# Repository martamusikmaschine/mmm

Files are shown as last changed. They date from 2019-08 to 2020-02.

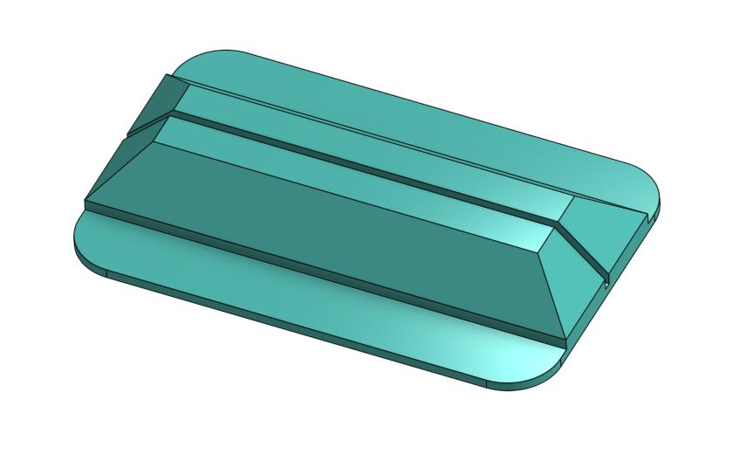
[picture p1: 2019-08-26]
3d/rfid_tag_44_29_foil_holder.jpg

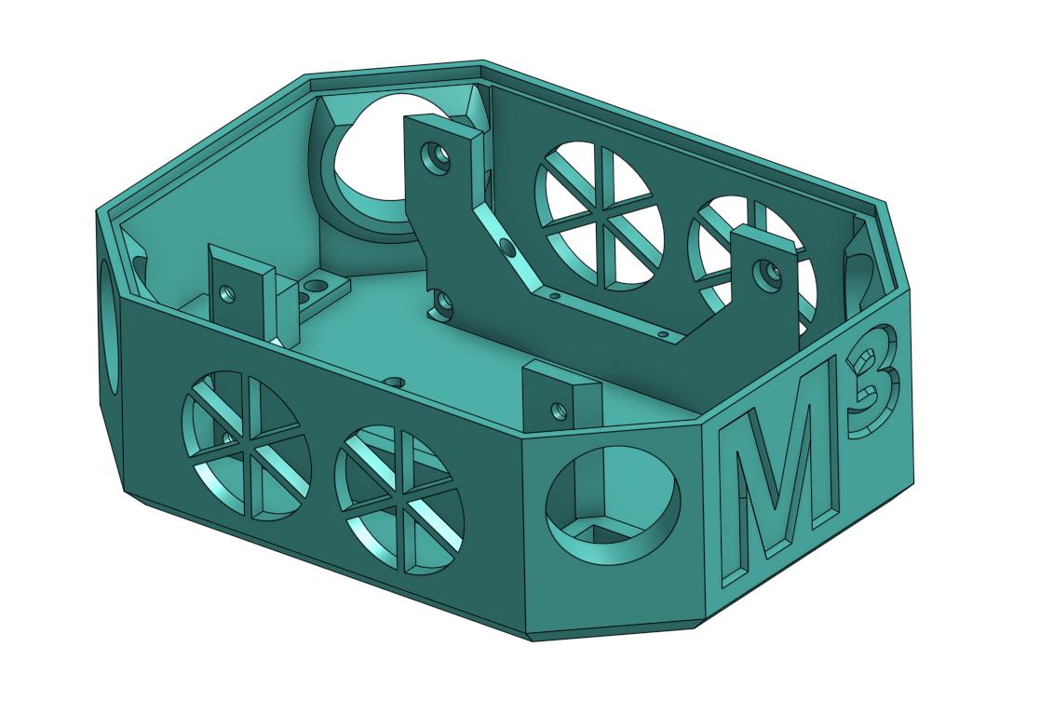
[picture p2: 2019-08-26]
3d/main_body.jpg

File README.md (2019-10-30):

# Marta Musik Maschine
Before doing anything, checkout the associated blog post series at [martamusikmaschine.com](https://martamusikmaschine.com).

Marta Musik Maschine is a DIY, RFID enabled, multi-purpose, audio and light device for kids. It's open source and you can build one yourself. It's not hard at all, I promise.

This repository contains all the code needed on the Raspberry Pi, a KiCad project that enables you to etch/order a PCB and a few stl models that you can print on a 3D printer.

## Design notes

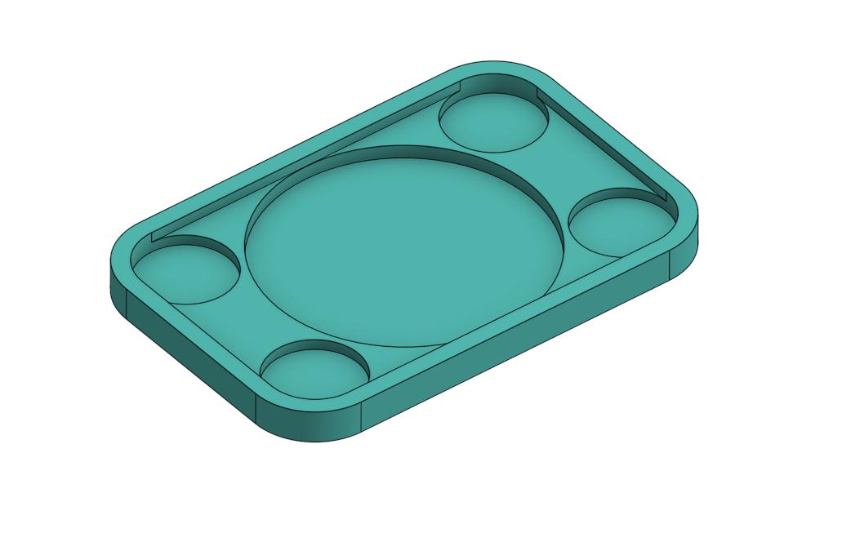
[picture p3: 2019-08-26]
3d/rfid_tag_44_29_base.jpg

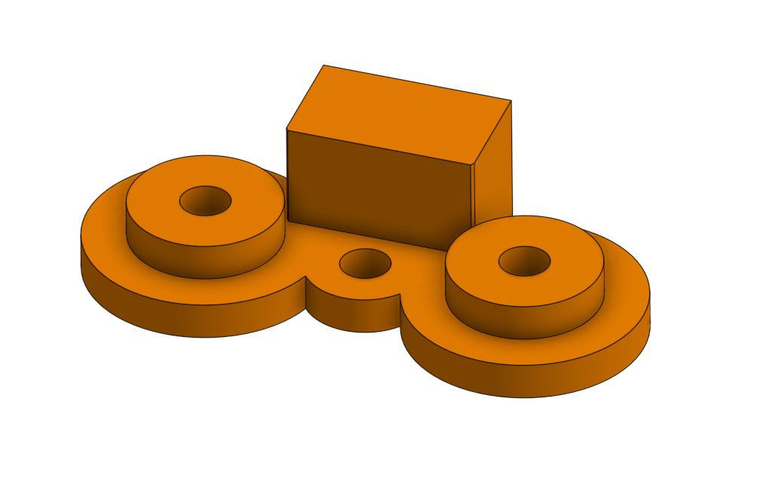
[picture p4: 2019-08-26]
3d/rfid_reader_magnet_cap.jpg

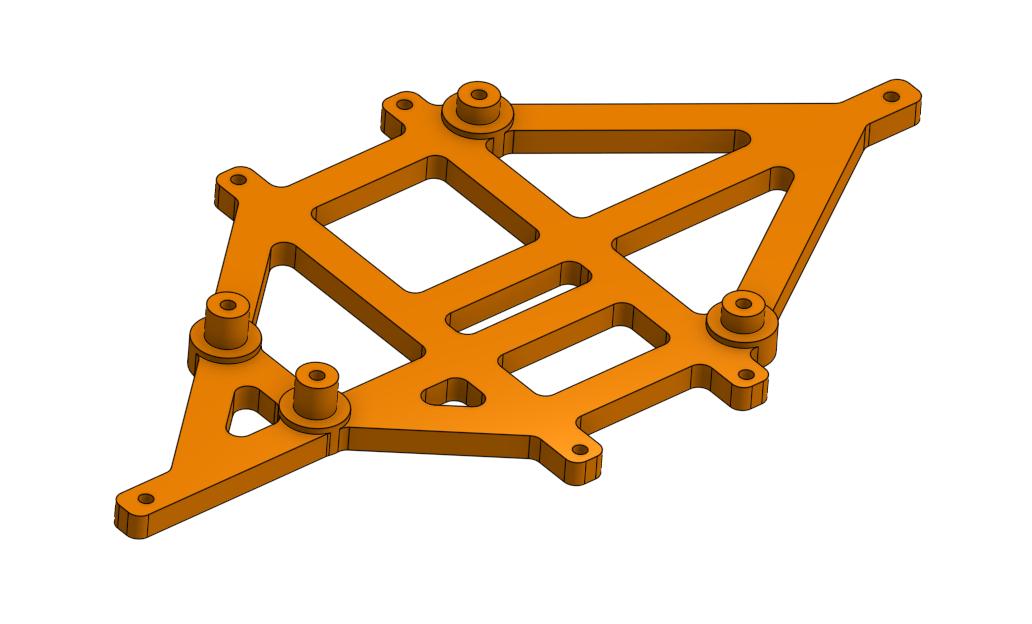
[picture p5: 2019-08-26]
3d/pcb_holder.jpg

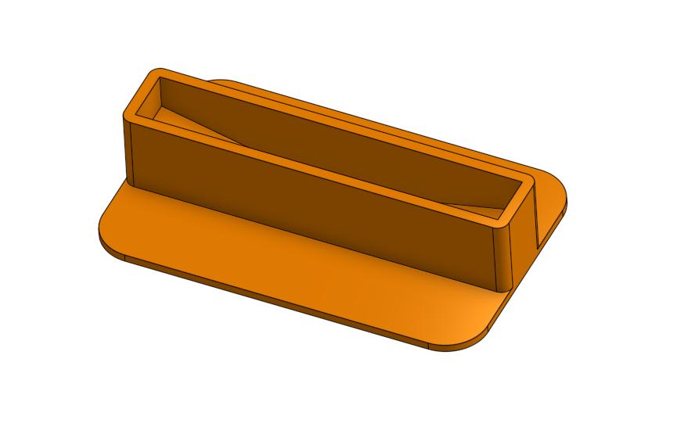
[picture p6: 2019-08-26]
3d/rfid_tag_44_29_photo_holder.jpg

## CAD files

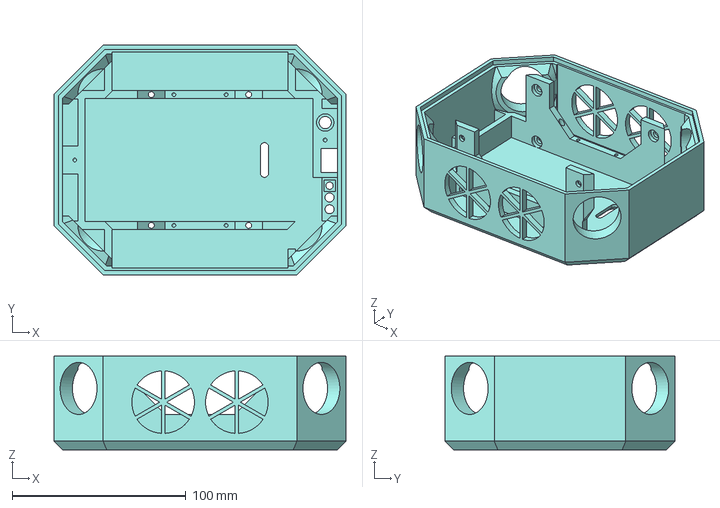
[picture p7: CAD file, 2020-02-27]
3d/main_body.step
168.0 x 132.2 x 54.0 mm

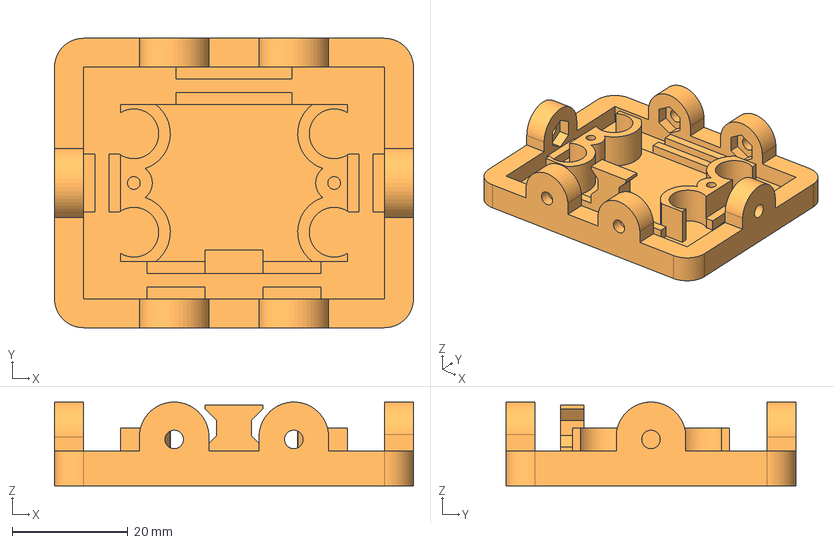
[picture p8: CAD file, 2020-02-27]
3d/rfid_reader_main.step
62.0 x 50.0 x 14.5 mm

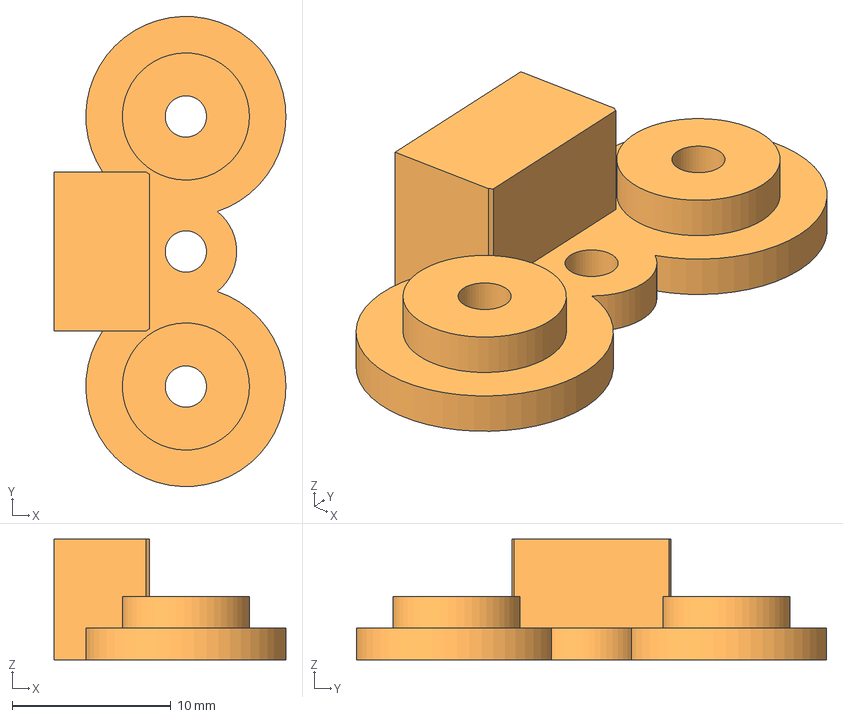
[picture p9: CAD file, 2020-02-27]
3d/rifd_reader_magnet_cap.step
14.6 x 29.6 x 7.60 mm

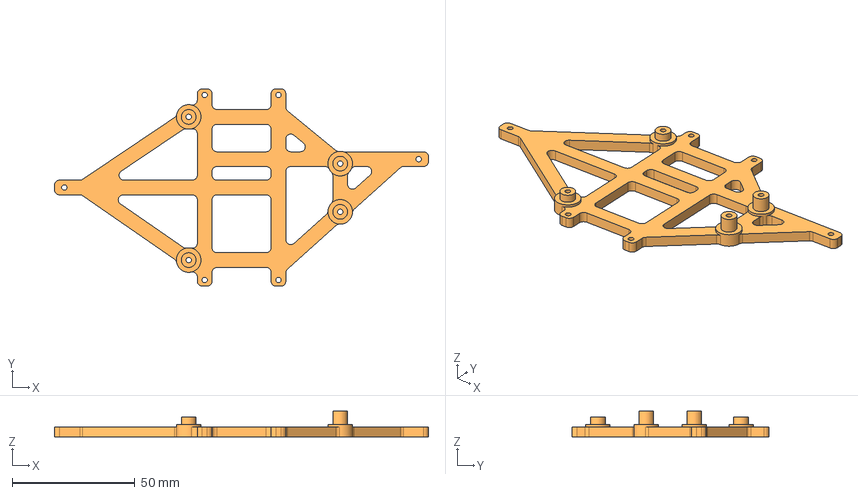
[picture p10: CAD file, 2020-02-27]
3d/pcb_holder.step
152.0 x 80.2 x 10.5 mm

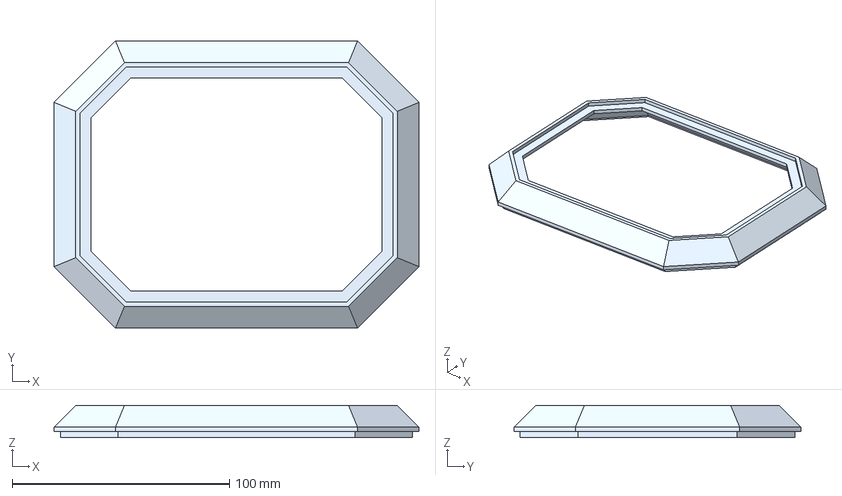
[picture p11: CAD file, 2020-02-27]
3d/led_ring.step
168.0 x 132.2 x 14.8 mm

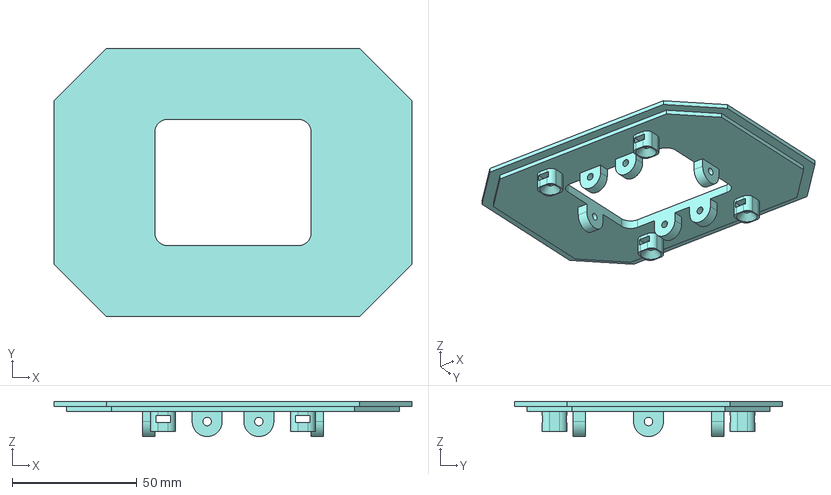
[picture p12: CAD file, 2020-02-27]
3d/top_plate.step
143.2 x 107.4 x 14.0 mm

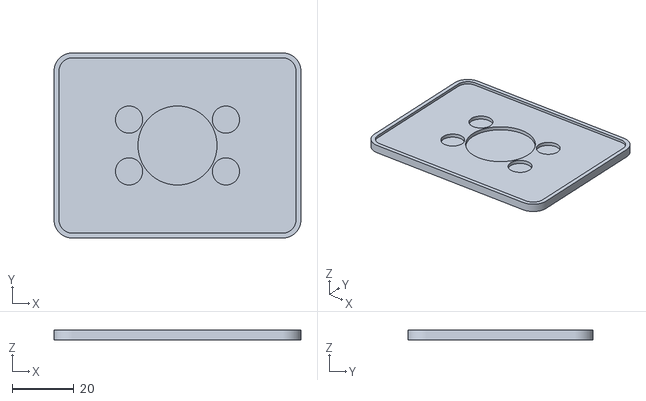
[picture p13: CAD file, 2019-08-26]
3d/rfid_tag_80_60_base.stl
80.0 x 60.0 x 3.10

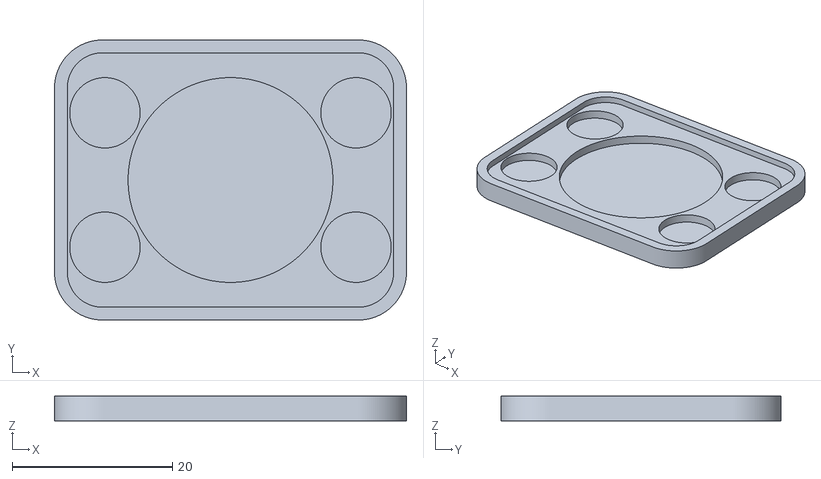
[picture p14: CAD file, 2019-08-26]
3d/rfid_tag_44_35_base.stl
44.0 x 35.0 x 3.10

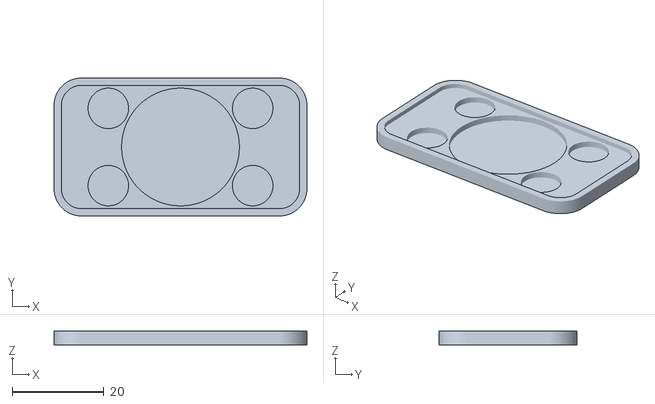
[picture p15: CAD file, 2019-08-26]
3d/rfid_tag_55_30_base.stl
55.0 x 30.0 x 3.10

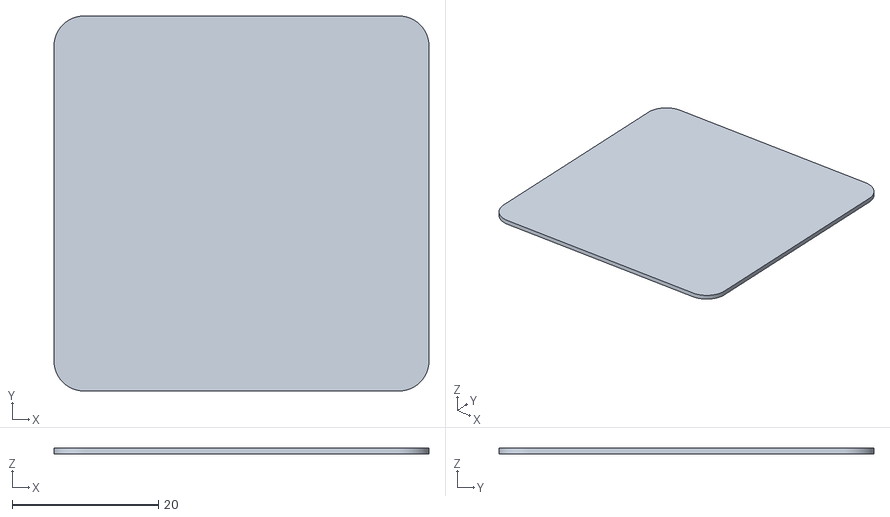
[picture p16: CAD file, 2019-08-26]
3d/rfid_tag_55_55_cap.stl
51.2 x 51.2 x 0.8

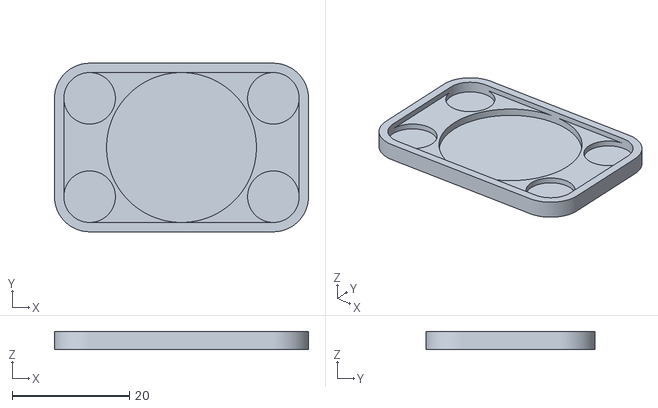
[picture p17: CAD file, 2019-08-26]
3d/rfid_tag_44_29_base.stl
43.4 x 28.8 x 3.10

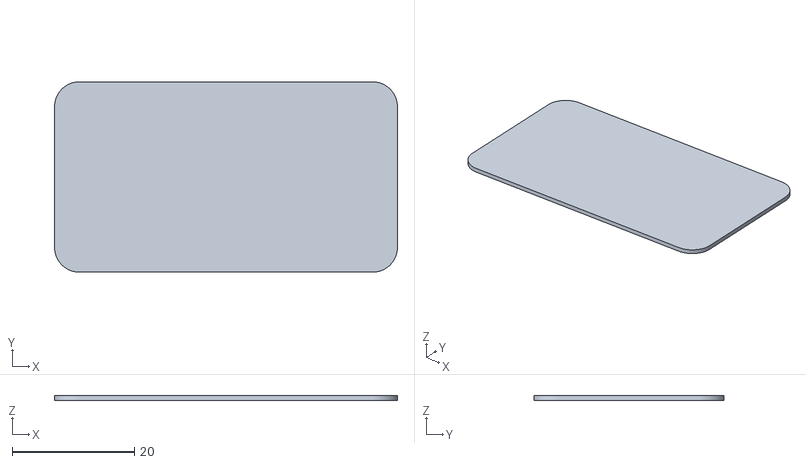
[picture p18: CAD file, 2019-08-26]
3d/rfid_tag_60_35_cap.stl
56.2 x 31.2 x 0.8

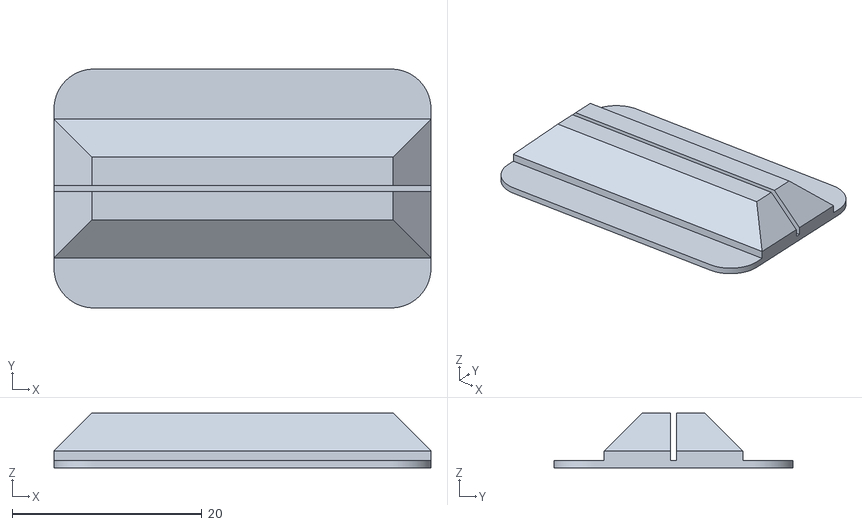
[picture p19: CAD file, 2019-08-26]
3d/rfid_tag_44_29_foil_holder.stl
39.8 x 25.2 x 5.80

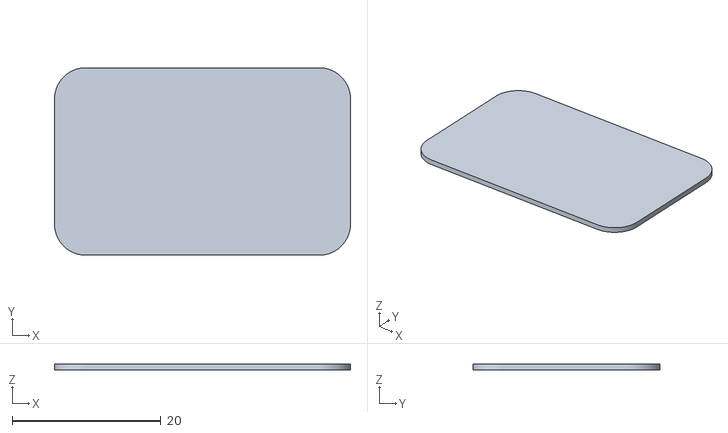
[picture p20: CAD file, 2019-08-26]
3d/rfid_tag_44_29_cap.stl
39.8 x 25.2 x 0.8

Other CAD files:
3d/rfid_reader_magnet_cap.iges
3d/rfid_tag_44_29_photo_holder.stl
3d/rfid_tag_50_30_base.stl
3d/rfid_tag_80_30_cap.stl
3d/led_ring.iges
3d/led_ring.stl
3d/main_body.iges
3d/main_body.stl
3d/pcb_holder.iges
3d/pcb_holder.stl
3d/rfid_reader_magnet_cap.stl
3d/rfid_reader_main.iges
3d/rfid_reader_main.stl
3d/rfid_tag_44_35_cap.stl
3d/rfid_tag_50_30_cap.stl
3d/rfid_tag_50_35_base.stl
3d/rfid_tag_50_35_cap.stl
3d/rfid_tag_50_50_base.stl
3d/rfid_tag_50_50_cap.stl
3d/rfid_tag_55_30_cap.stl
3d/rfid_tag_55_55_base.stl
3d/rfid_tag_60_35_base.stl
3d/rfid_tag_62_32_base.stl
3d/rfid_tag_62_32_cap.stl
3d/rfid_tag_80_30_base.stl
3d/rfid_tag_80_60_cap.stl
3d/top_plate.iges
3d/top_plate.stl

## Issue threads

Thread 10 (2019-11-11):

CAD files

nick-traeger, 2019-11-11:
Hello, thanks for publishing this great project! I would like to build a similar box and change the design of the box a bit. Is it possible to get the CAD files - not just the STL files?

martamusikmaschine, 2020-02-27:
Hey, so sorry. I didn't get any notification and haven't looked at the repository for quite some time. I'll upload IGES and STEP files for the main components as well. Unfortunately there's no way to export CAD files from OnShape.

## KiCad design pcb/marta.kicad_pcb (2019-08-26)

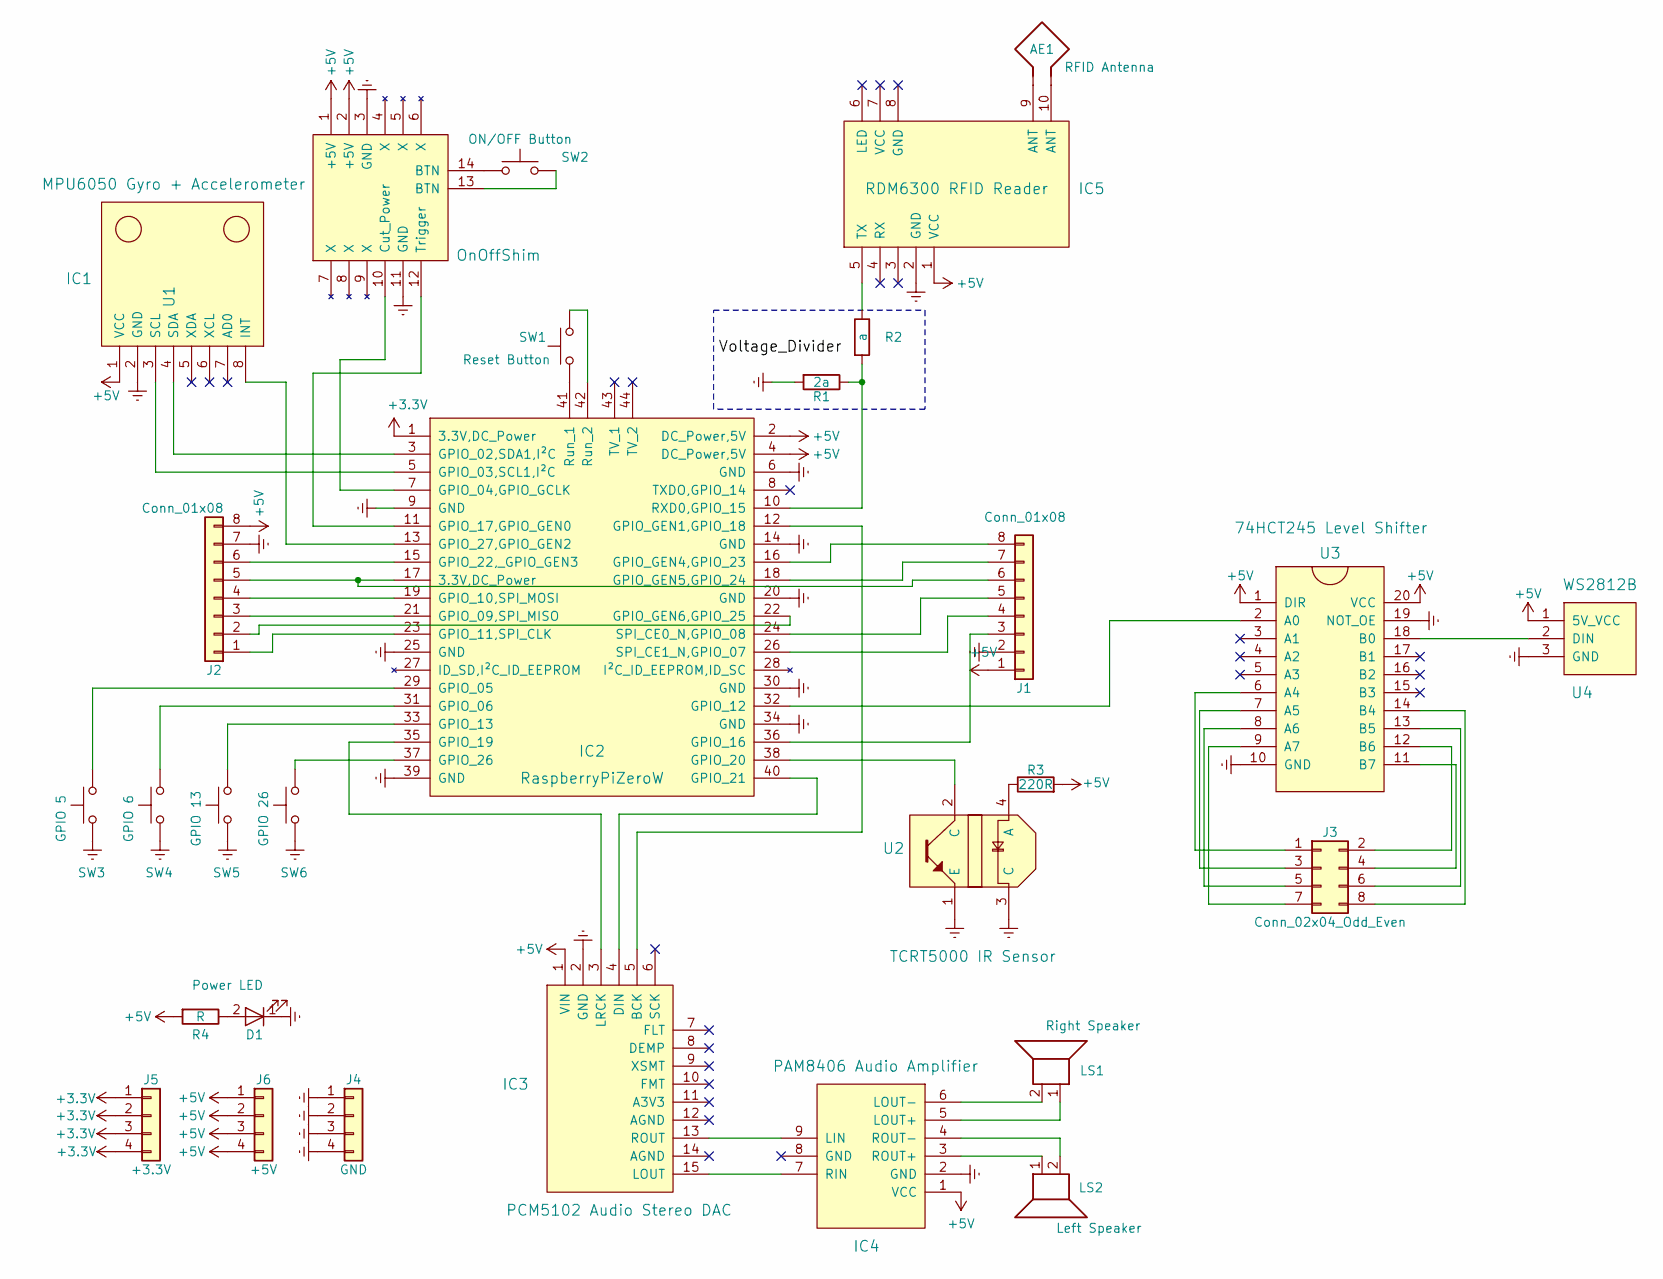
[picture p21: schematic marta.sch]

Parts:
AE1: RFID Antenna; JST_XH_B02B-XH-A_02x2.50mm_Straight
D1: Power LED; JST_XH_B02B-XH-A_02x2.50mm_Straight
IC1: MPU6050 Gyro + Accelerometer; MPU6050
IC2: RaspberryPiZeroW; RaspberryPiZeroW_UpSideDown
IC3: PCM5102 Audio Stereo DAC; PCM5102
IC4: PAM8406 Audio Amplifier; PAM8406
IC5: RDM6300 RFID Reader; RDM6300
J1, J2: Conn_01x08; JST_XH_B08B-XH-A_08x2.50mm_Straight
J3: Conn_02x04_Odd_Even; Pin_Header_Straight_2x04_Pitch2.54mm
J4: GND; Pin_Header_Straight_1x04_Pitch2.54mm
J5: +3.3V; Pin_Header_Straight_1x04_Pitch2.54mm
J6: +5V; Pin_Header_Straight_1x04_Pitch2.54mm
LS1: Right Speaker; JST_XH_B02B-XH-A_02x2.50mm_Straight
LS2: Left Speaker; JST_XH_B02B-XH-A_02x2.50mm_Straight
R1: 2a; R_Axial_DIN0207_L6.3mm_D2.5mm_P10.16mm_Horizontal
R2: a; R_Axial_DIN0207_L6.3mm_D2.5mm_P10.16mm_Horizontal
R3: 220R; R_Axial_DIN0207_L6.3mm_D2.5mm_P10.16mm_Horizontal
R4: R; R_Axial_DIN0207_L6.3mm_D2.5mm_P10.16mm_Horizontal
SW1: Reset Button; JST_XH_B02B-XH-A_02x2.50mm_Straight
SW2: ON/OFF Button; JST_XH_B02B-XH-A_02x2.50mm_Straight
SW3: GPIO 5; JST_XH_B02B-XH-A_02x2.50mm_Straight
SW4: GPIO 6; JST_XH_B02B-XH-A_02x2.50mm_Straight
SW5: GPIO 13; JST_XH_B02B-XH-A_02x2.50mm_Straight
SW6: GPIO 26; JST_XH_B02B-XH-A_02x2.50mm_Straight
U1: OnOffShim
U2: TCRT5000 IR Sensor; JST_XH_B04B-XH-A_04x2.50mm_Straight
U3: 74HCT245 Level Shifter; DIP-20_W7.62mm
U4: WS2812B; Pin_Header_Straight_1x03_Pitch2.54mm

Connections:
+3V3: IC2.1 (3.3V,DC_Power), J5.1, J5.2, J5.3, J5.4
+5V: IC1.1 (VCC), IC2.2 (DC_Power,5V), IC2.4 (DC_Power,5V), IC3.1 (VIN), IC4.1 (VCC), IC5.1 (VCC), J1.1, J2.8, J6.1, J6.2, J6.3, J6.4, R3.2, R4.2, U1.1 (+5V), U1.2 (+5V), U3.1 (DIR), U3.20 (VCC), U4.1 (5V_VCC)
GNDREF: D1.1 (K), IC1.2 (GND), IC2.6 (GND), IC2.9 (GND), IC2.14 (GND), IC2.20 (GND), IC2.25 (GND), IC2.30 (GND), IC2.34 (GND), IC2.39 (GND), IC3.2 (GND), IC4.2 (GND), IC5.2 (GND), J1.2, J2.7, J4.1, J4.2, J4.3, J4.4, R1.2, SW3.1, SW4.1, SW5.1, SW6.1, U1.3 (GND), U1.11 (GND), U2.1 (E), U2.3 (C), U3.10 (GND), U3.19 (NOT_OE), U4.3 (GND)
unnamed: AE1.1, IC5.9 (ANT)
unnamed: AE1.2, IC5.10 (ANT)
unnamed: D1.2 (A), R4.1
unnamed: IC1.3 (SCL), IC2.5 (GPIO_03,SCL1,I²C)
unnamed: IC1.4 (SDA), IC2.3 (GPIO_02,SDA1,I²C)
unnamed: IC1.8 (INT), IC2.13 (GPIO_27,GPIO_GEN2)
unnamed: IC2.7 (GPIO_04,GPIO_GCLK), U1.10 (Cut_Power)
unnamed: IC2.10 (RXD0,GPIO_15), R1.1, R2.2
unnamed: IC2.11 (GPIO_17,GPIO_GEN0), U1.12 (Trigger)
unnamed: IC2.12 (GPIO_GEN1,GPIO_18), IC3.5 (BCK)
unnamed: IC2.15 (GPIO_22,_GPIO_GEN3), J2.6
unnamed: IC2.16 (GPIO_GEN4,GPIO_23), J1.8
unnamed: IC2.17 (3.3V,DC_Power), J1.6, J2.5
unnamed: IC2.18 (GPIO_GEN5,GPIO_24), J1.7
unnamed: IC2.19 (GPIO_10,SPI_MOSI), J2.4
unnamed: IC2.21 (GPIO_09,SPI_MISO), J2.3
unnamed: IC2.22 (GPIO_GEN6,GPIO_25), J2.2
unnamed: IC2.23 (GPIO_11,SPI_CLK), J2.1
unnamed: IC2.24 (SPI_CE0_N,GPIO_08), J1.5
unnamed: IC2.26 (SPI_CE1_N,GPIO_07), J1.4
unnamed: IC2.29 (GPIO_05), SW3.2
unnamed: IC2.31 (GPIO_06), SW4.2
unnamed: IC2.32 (GPIO_12), U3.2 (A0)
unnamed: IC2.33 (GPIO_13), SW5.2
unnamed: IC2.35 (GPIO_19), IC3.3 (LRCK)
unnamed: IC2.36 (GPIO_16), J1.3
unnamed: IC2.37 (GPIO_26), SW6.2
unnamed: IC2.38 (GPIO_20), U2.2 (C)
unnamed: IC2.40 (GPIO_21), IC3.4 (DIN)
unnamed: IC2.41 (Run_1), SW1.1
unnamed: IC2.42 (Run_2), SW1.2
unnamed: IC3.13 (ROUT), IC4.9 (LIN)
unnamed: IC3.15 (LOUT), IC4.7 (RIN)
unnamed: IC4.3 (ROUT+), LS2.1
unnamed: IC4.4 (ROUT-), LS2.2
unnamed: IC4.5 (LOUT+), LS1.1
unnamed: IC4.6 (LOUT-), LS1.2
unnamed: IC5.5 (TX), R2.1
unnamed: J3.1, U3.6 (A4)
unnamed: J3.2, U3.12 (B6)
unnamed: J3.3, U3.7 (A5)
unnamed: J3.4, U3.11 (B7)
unnamed: J3.5, U3.8 (A6)
unnamed: J3.6, U3.13 (B5)
unnamed: J3.7, U3.9 (A7)
unnamed: J3.8, U3.14 (B4)
unnamed: R3.1, U2.4 (A)
unnamed: SW2.1, U1.14 (BTN)
unnamed: SW2.2, U1.13 (BTN)
unnamed: U3.18 (B0), U4.2 (DIN)

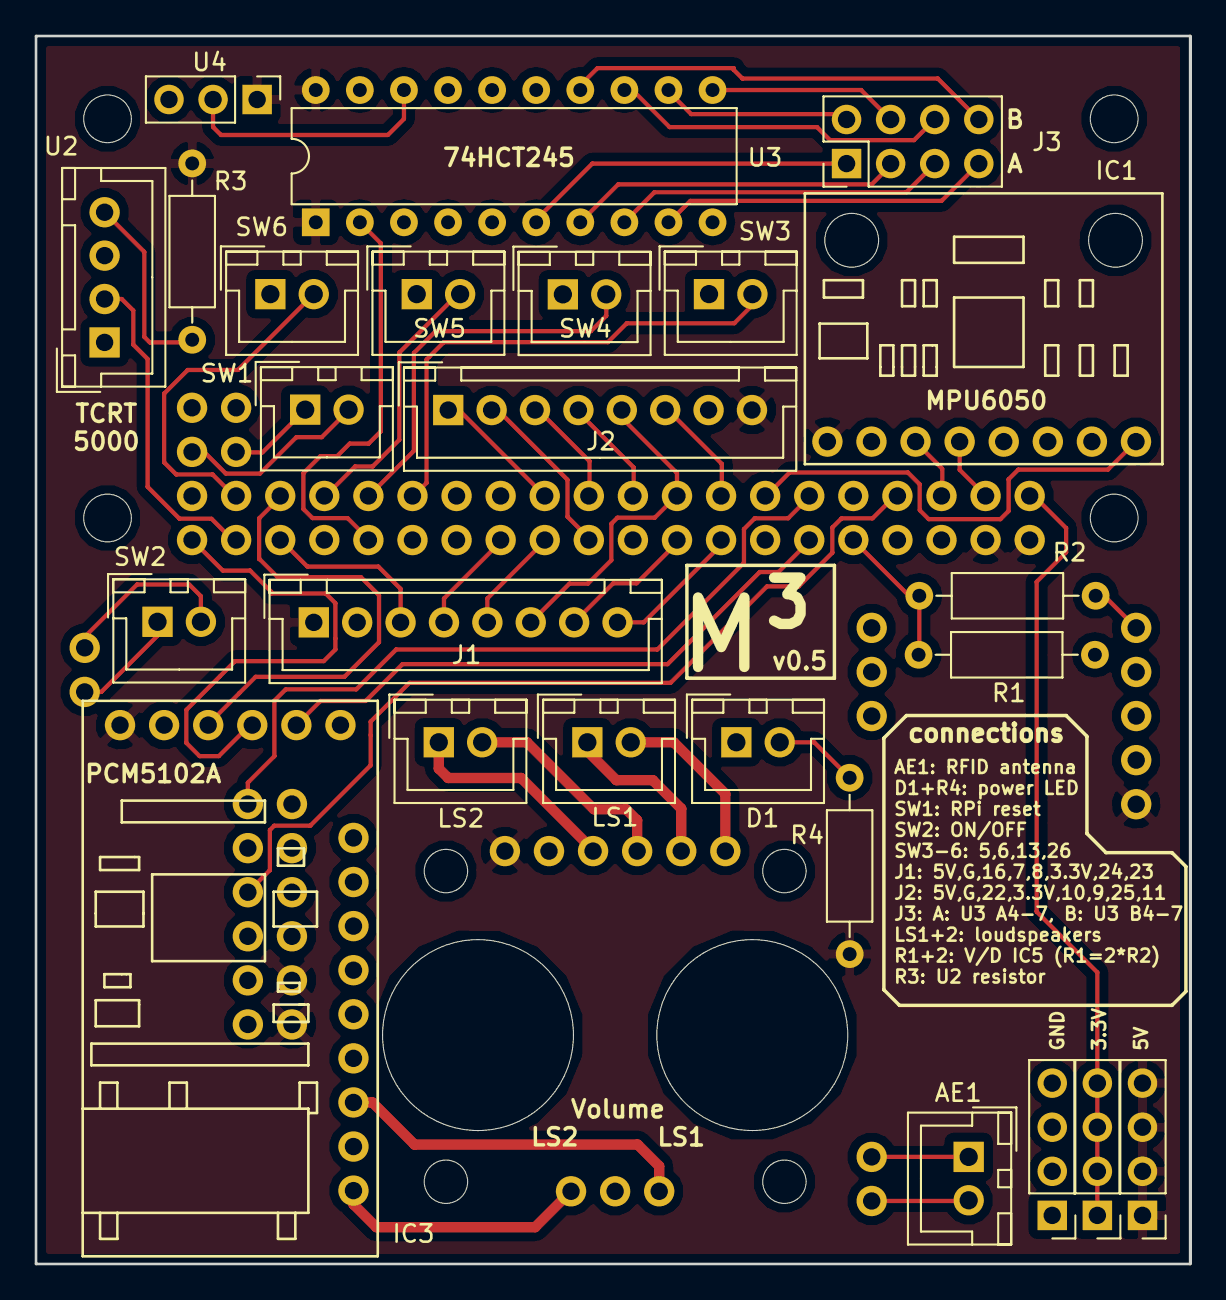
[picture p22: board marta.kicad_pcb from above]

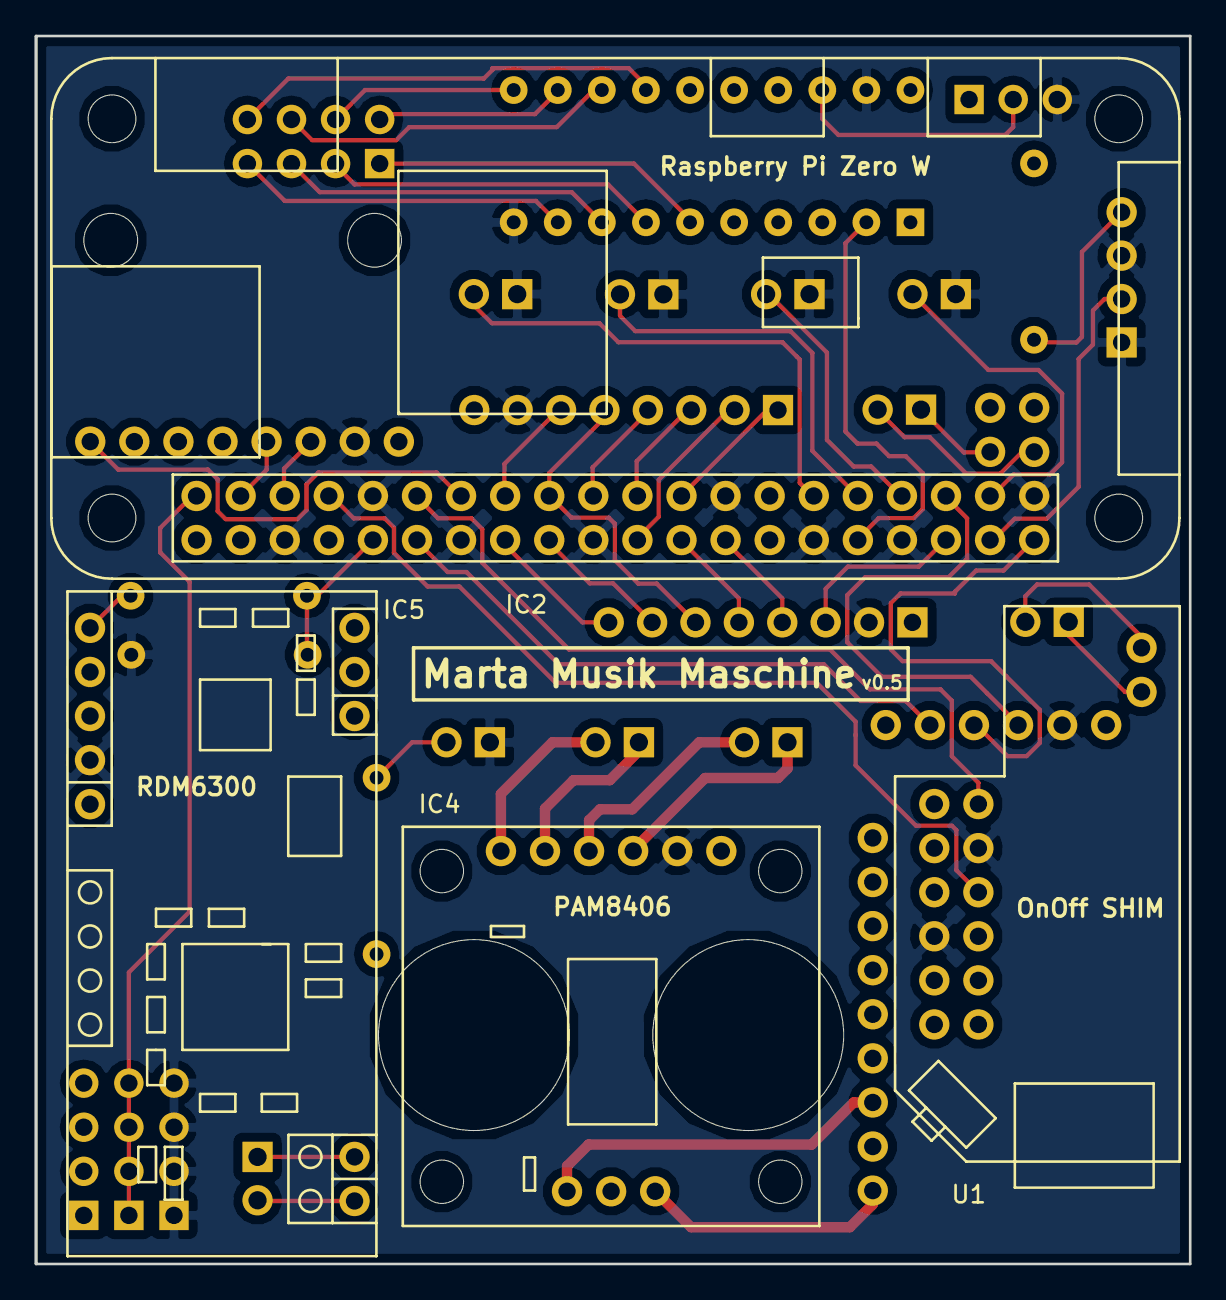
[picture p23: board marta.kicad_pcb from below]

Board: 2 copper layers, 66.5 x 70.8 mm, 29 parts (4 on the bottom side), 53 nets.

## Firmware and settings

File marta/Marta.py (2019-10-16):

# system
from logging import handlers, getLogger, DEBUG, Formatter, StreamHandler
from sys import stdout, argv
from Queue import Queue, Empty
from time import sleep, strftime
from signal import signal, SIGINT
from os import environ
from monotonic import monotonic as mtime
import traceback

import Buttons
from MartaHandler import MartaHandler
from LEDStrip import LEDStrip
from MPG123 import MPG123Player
from MPU import MPU
from RFIDReader import RFIDReader
from TagToHandler import TAG_TO_HANDLER

debug = getLogger('     Marta').debug

MARTA_BASE_DIR = environ["MARTA"]


class Marta(object):
    ################
    # EVENTS
    EVENT_SONG_STOPPED = 0
    EVENT_RFID_TAG = 1
    EVENT_BUTTON = 2
    EVENT_MPG123_ERROR = 3
    EVENT_ROTATION = 4
    EVENT_INTERRUPT = 5

    EXIT_DEBUG = 2

    EVENT_HUMAN_READABLE = [
        "EVENT_SONG_STOPPED",
        "EVENT_TAG",
        "EVENT_BUTTON",
        "EVENT_MPG123_ERROR",
        "EVENT_ROTATION",
        "EVENT_INTERRUPT"
    ]

    ################
    # SPECIAL TAGS

    INTERRUPT_TAG = "5600C7AC4B76"

    ################
    # AUDIO

    START_SOUND_PATH = MARTA_BASE_DIR + "/audio/system/startup.mp3"
    SHUTDOWN_SOUND_PATH = MARTA_BASE_DIR + "/audio/system/shutdown.mp3"
    SYSTEM_SOUND_VOLUME = 2

    def __init__(self):
        self.__message_queue = Queue()
        Buttons.setup_gpio(lambda pin, millis: self.__message_queue.put([Marta.EVENT_BUTTON, pin, millis]))

        if Buttons.is_pushed(Buttons.POWER_BUTTON) and Buttons.is_pushed(Buttons.RED_BUTTON):
            Buttons.terminate()
            debug("Early user interrupt!")
            exit(Marta.EXIT_DEBUG)

        self.player = MPG123Player(lambda: self.__message_queue.put([Marta.EVENT_SONG_STOPPED]),
                                   lambda: self.__message_queue.put([Marta.EVENT_MPG123_ERROR]),
                                   volume=Marta.SYSTEM_SOUND_VOLUME)

        self.leds = LEDStrip()

        self.player.load_track_from_file(Marta.START_SOUND_PATH)
        self.leds.startup()
        self.player.play_track()

        # hacky because MPG123Player is async
        while not self.player.is_track_playing():
            sleep(0.05)

        # True = GPIO.HIGH = 1
        # False = GPIO.LOW = 0
        g = True
        while self.player.is_track_playing():
            Buttons.set_status_led(g)
            sleep(0.2)
            g = not g

        Buttons.set_status_led(0)

        # Empty q after short period of time (player stop event and button pushes)
        sleep(0.1)
        while not self.__message_queue.empty():
            self.__message_queue.get(block=False)

        self.mpu = MPU(period=1, threshold=5,
                       rotation_receiver=lambda x, y: self.__message_queue.put([Marta.EVENT_ROTATION, x, y]))

        self.rfid_reader = RFIDReader(lambda tag: self.__message_queue.put([Marta.EVENT_RFID_TAG, tag]))

    def interrupt(self):
        self.__message_queue.put([Marta.EVENT_INTERRUPT])

    def message_loop(self):

        current_handler = TAG_TO_HANDLER["default"].get_instance(self)
        max_mono_time = mtime() + current_handler.initialize()

        while True:
            now = mtime()
            debug("now = " + str(now))

            if now >= max_mono_time:
                debug("timeout occurred")
                break

            timeout = max_mono_time - now
            debug("waiting for " + str(timeout))
            try:
                msg = self.__message_queue.get(block=True, timeout=timeout)
            except Empty:
                # If a time change (due to network time availability) occurs while waiting for an event,
                # Queue.get will return Empty early:

                # 14:46:31.368 | main | now = 54.502526
                # 14:46:31.380 | main | waiting for 299.955775
                # -- NOW THE TIME CHANGE OCCURS --
                # 19:29:13.403 | main | timeout @ 67.323505
                # 19:29:13.410 | main | Terminating!

                # Instead of breaking here, we just continue, because we have another check on top of this function
                #  which checks the timeout again but using a monotonic timer
                debug("possible timeout @ " + str(mtime()))
                continue

            event = msg[0]
            params = msg[1:]

            if event == Marta.EVENT_INTERRUPT:
                debug("Critical: Interrupt event!")
                break

            elif event == Marta.EVENT_MPG123_ERROR:
                debug("Critical: MPG123 error event!")
                break

            elif event == Marta.EVENT_BUTTON and params[0] == Buttons.POWER_BUTTON:
                debug("Critical: Power button event!")
                break

            elif event == Marta.EVENT_RFID_TAG:
                tag = params[0]

                if tag == Marta.INTERRUPT_TAG:
                    debug("Critical: Interrupt tag event!")
                    exit(Marta.EXIT_DEBUG)
                    break

                if tag in TAG_TO_HANDLER:
                    current_handler.uninitialize()
                    current_handler = TAG_TO_HANDLER[tag].get_instance(self)
                    current_handler.initialize()

            debug(Marta.EVENT_HUMAN_READABLE[event] + ": " + str(params))
            if event == Marta.EVENT_ROTATION:
                return_val = current_handler.rotation_event(params[0], params[1])
            elif event == Marta.EVENT_SONG_STOPPED:
                return_val = current_handler.player_stop_event()
            elif event == Marta.EVENT_RFID_TAG:
                return_val = current_handler.rfid_tag_event(params[0])
            elif event == Marta.EVENT_BUTTON:
                return_val = current_handler.button_event(params[0], params[1])
            else:
                raise Exception("Unknown event: " + str(event))

            if return_val is None:
                debug("not changing the timeout")
            else:
                if return_val == MartaHandler.EVENT_HANDLER_DONE:
                    debug("This event handler is done.")
                    current_handler.uninitialize()
                    current_handler = TAG_TO_HANDLER["default"].get_instance(self)
                    return_val = current_handler.initialize()
                max_mono_time = mtime() + return_val

        current_handler.uninitialize()

    def terminate(self):
        debug("Terminating!")

        try:
            self.player.set_volume(Marta.SYSTEM_SOUND_VOLUME)
            self.player.set_pitch(100)
            self.player.load_track_from_file(Marta.SHUTDOWN_SOUND_PATH)
            self.player.play_track()
        except:
            pass

        try:
            self.leds.shutdown()
        except:
            pass

        try:
            for i in range(20):
                Buttons.set_status_led(i % 2)
                sleep(0.2)
        except:
            pass

        try:
            self.mpu.terminate()
        except:
            pass

        try:
            self.player.terminate()
        except:
            pass

        try:
            self.rfid_reader.terminate()
        except:
            pass

        try:
            self.leds.terminate()
        except:
            pass

        try:
            for i in range(10):
                Buttons.set_status_led(i % 2)
                sleep(0.2)
        except:
            pass

        try:
            Buttons.terminate()
        except:
            pass


def main():
    logger = getLogger('')
    logger.setLevel(DEBUG)
    formatter = Formatter("%(asctime)s.%(msecs)03d | %(name)s |    %(message)s", "%H:%M:%S")

    if "log2stdout" in argv:
        ch = StreamHandler(stdout)
        ch.setFormatter(formatter)
        logger.addHandler(ch)

    fh = handlers.RotatingFileHandler(MARTA_BASE_DIR + "/logs/mmm.log", maxBytes=(1024 * 1024 * 10), backupCount=10)
    fh.setFormatter(formatter)
    logger.addHandler(fh)

    debug("#################################################")
    debug("#                  INITIALIZED                  #")
    debug("#              " + strftime("%Y-%m-%d %H:%M:%S") + "              #")
    debug("#################################################")

    debug("""
    
                            _    _        _                                _          
                           | |  | |      | |                              | |         
                           | |  | |  ___ | |  ___  ___   _ __ ___    ___  | |_  ___   
                           | |/\| | / _ \| | / __|/ _ \ | '_ ` _ \  / _ \ | __|/ _ \  
                           \  /\  /|  __/| || (__| (_) || | | | | ||  __/ | |_| (_) | 
                            \/  \/  \___||_| \___|\___/ |_| |_| |_| \___|  \__|\___/  
                                                           
                                                           
    
    MMMMMMMM               MMMMMMMM     MMMMMMMM               MMMMMMMM     MMMMMMMM               MMMMMMMM
    M:::::::M             M:::::::M     M:::::::M             M:::::::M     M:::::::M             M:::::::M
    M::::::::M           M::::::::M     M::::::::M           M::::::::M     M::::::::M           M::::::::M
    M:::::::::M         M:::::::::M     M:::::::::M         M:::::::::M     M:::::::::M         M:::::::::M
    M::::::::::M       M::::::::::M     M::::::::::M       M::::::::::M     M::::::::::M       M::::::::::M
    M:::::::::::M     M:::::::::::M     M:::::::::::M     M:::::::::::M     M:::::::::::M     M:::::::::::M
    M:::::::M::::M   M::::M:::::::M     M:::::::M::::M   M::::M:::::::M     M:::::::M::::M   M::::M:::::::M
    M::::::M M::::M M::::M M::::::M     M::::::M M::::M M::::M M::::::M     M::::::M M::::M M::::M M::::::M
    M::::::M  M::::M::::M  M::::::M     M::::::M  M::::M::::M  M::::::M     M::::::M  M::::M::::M  M::::::M
    M::::::M   M:::::::M   M::::::M     M::::::M   M:::::::M   M::::::M     M::::::M   M:::::::M   M::::::M
    M::::::M    M:::::M    M::::::M     M::::::M    M:::::M    M::::::M     M::::::M    M:::::M    M::::::M
    M::::::M     MMMMM     M::::::M     M::::::M     MMMMM     M::::::M     M::::::M     MMMMM     M::::::M
    M::::::M               M::::::M     M::::::M               M::::::M     M::::::M               M::::::M
    M::::::M               M::::::M     M::::::M               M::::::M     M::::::M               M::::::M
    M::::::M               M::::::M     M::::::M               M::::::M     M::::::M               M::::::M
    MMMMMMMM               MMMMMMMM     MMMMMMMM               MMMMMMMM     MMMMMMMM               MMMMMMMM
    
    """)

    exit_val = 0

    debug("initializing")
    marta = Marta()
    signal(SIGINT, lambda s, f: marta.interrupt())

    debug("looping")
    try:
        marta.message_loop()
    except Exception as e:
        debug("excepted: " + str(e))
        debug(traceback.format_exc())
        exit_val = 1

    marta.terminate()

    debug("exiting")
    exit(exit_val)


if __name__ == "__main__":
    main()

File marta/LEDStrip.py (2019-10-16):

from Queue import Queue, Empty

from neopixel import *
from threading import Thread
from logging import getLogger

debug = getLogger('  LEDStrip').debug


class SleepInterruptedException(Exception):
    def __init__(self, message):
        super(SleepInterruptedException, self).__init__("")
        self.msg = message


class LEDStrip(object):
    _LED_COUNT = 28  # Number of LED pixels.
    _LED_PIN = 12  # GPIO pin connected to the pixels (18 uses PWM!).
    _LED_FREQ_HZ = 800000  # LED signal frequency in hertz (usually 800khz)
    _LED_DMA = 10  # DMA channel to use for generating signal (try 10)
    _LED_BRIGHTNESS = 255  # Set to 0 for darkest and 255 for brightest
    _LED_INVERT = False  # True to invert the signal (when using NPN transistor level shift)
    _LED_CHANNEL = 0  # set to '1' for GPIOs 13, 19, 41, 45 or 53
    _LED_STRIP = ws.WS2811_STRIP_GRB  # Strip type and colour ordering

    _EVENT_TERMINATE = 0
    _EVENT_RAINBOW_DEMO = 1
    _EVENT_VOLUME = 2
    _EVENT_FADE_UP_AND_DOWN = 3
    _EVENT_STARTUP = 4
    _EVENT_SHUTDOWN = 5
    _EVENT_SONG = 6
    _EVENT_CLEAR = 7

    _EVENTS_HUMAN_READABLE = ["TERMINATE", "RAINBOW_DEMO", "VOLUME", "FADE_UP_AND_DOWN", "STARTUP", "SHUTDOWN", "SONG",
                              "CLEAR"]

    RED = Color(255, 0, 0)
    GREEN = Color(0, 255, 0)
    BLUE = Color(0, 0, 255)
    YELLOW = Color(255, 255, 0)
    PURPLE = Color(255, 0, 255)
    WHITE = Color(255, 255, 255)
    ORANGE = Color(0xFF, 0x8C, 0x00)

    _LEDS = range(_LED_COUNT)
    _VOLUME_LEDS = _LEDS[4:14]
    _LEDS_FROM_MIDDLE = _LEDS[2:] + _LEDS[:2]
    _LEDS_SONG = _LEDS_FROM_MIDDLE[2:-2]

    # Color gradient from Green to Red
    _VOLUME_LED_COLORS = [0x00FF00, 0x1CE200, 0x38C600, 0x55AA00, 0x718D00, 0x8D7100, 0xAA5500, 0xC63800, 0xE21C00,
                          0xFF0000]

    def __init__(self):
        self._strip = Adafruit_NeoPixel(LEDStrip._LED_COUNT, LEDStrip._LED_PIN, LEDStrip._LED_FREQ_HZ,
                                        LEDStrip._LED_DMA, LEDStrip._LED_INVERT, LEDStrip._LED_BRIGHTNESS,
                                        LEDStrip._LED_CHANNEL, LEDStrip._LED_STRIP)
        self._strip.begin()
        self._message_queue = Queue()

        self._led_controller_thread = Thread(target=self._control_leds)
        self._led_controller_thread.daemon = True
        self._led_controller_thread.start()

    def _control_leds(self):
        msg = None
        while True:
            msg = self._message_queue.get(block=True, timeout=None) if msg is None else msg

            event = msg[0]

            debug("event: %s", LEDStrip._EVENTS_HUMAN_READABLE[event])

            if event == LEDStrip._EVENT_TERMINATE:
                break

            # # Ignore if others are waiting
            # if not self._message_queue.empty():
            #     debug("ignoring that one...")
            #     continue

            try:
                if event == LEDStrip._EVENT_RAINBOW_DEMO:
                    self._rainbow_cycle_animation()

                elif event == LEDStrip._EVENT_VOLUME:
                    self._volume_animation(msg[1])

                elif event == LEDStrip._EVENT_FADE_UP_AND_DOWN:
                    self._fade_animation(msg[1])

                elif event == LEDStrip._EVENT_STARTUP:
                    self._startup_animation()

                elif event == LEDStrip._EVENT_SHUTDOWN:
                    self._shutdown_animation()

                elif event == LEDStrip._EVENT_SONG:
                    self._song_animation(msg[1], msg[2], msg[3])

                elif event == LEDStrip._EVENT_CLEAR:
                    self._clear_all()

                msg = None

            except SleepInterruptedException as sie:
                msg = sie.msg

    def _sleep(self, timeout):
        try:
            raise SleepInterruptedException(self._message_queue.get(block=True, timeout=timeout))
        except Empty:
            pass

    def startup(self):
        self._message_queue.put([LEDStrip._EVENT_STARTUP])

    def shutdown(self):
        self._message_queue.put([LEDStrip._EVENT_SHUTDOWN])

    def rainbow_demo(self):
        self._message_queue.put([LEDStrip._EVENT_RAINBOW_DEMO])

    def volume(self, volume):
        self._message_queue.put([LEDStrip._EVENT_VOLUME, volume])

    def song(self, i, n, forward=True):
        self._message_queue.put([LEDStrip._EVENT_SONG, i, n, forward])

    def fade_up_and_down(self, color):
        self._message_queue.put([LEDStrip._EVENT_FADE_UP_AND_DOWN, color])

    def clear(self):
        self._message_queue.put([LEDStrip._EVENT_CLEAR])

    def _clear_all(self):
        for i in range(LEDStrip._LED_COUNT):
            self._strip.setPixelColor(i, 0)
        self._strip.show()

    def _fade_up(self, leds, colors):
        rgbs = []
        for color in colors:
            rgbs.append(((color >> 16) & 255, (color >> 8) & 255, color & 255))

        for c in range(11):
            for i in range(len(leds)):
                self._strip.setPixelColor(leds[i], Color(int(round(rgbs[i][0] * 0.1 * c)),
                                                         int(round(rgbs[i][1] * 0.1 * c)),
                                                         int(round(rgbs[i][2] * 0.1 * c))))
            self._strip.show()
            self._sleep(0.05)

    def _fade_down(self, leds):
        initial_rgbs = []
        for led in leds:
            color = self._strip.getPixelColor(led)
            initial_rgbs.append(((color >> 16) & 255, (color >> 8) & 255, color & 255))

        for c in range(-9, 1):
            for i in range(len(leds)):
                self._strip.setPixelColor(leds[i], Color(int(round(initial_rgbs[i][0] * -0.1 * c)),
                                                         int(round(initial_rgbs[i][1] * -0.1 * c)),
                                                         int(round(initial_rgbs[i][2] * -0.1 * c))))
            self._strip.show()
            self._sleep(0.05)

    def _fade_up_and_down(self, leds, colors):
        self._fade_up(leds, colors)
        self._sleep(0.5)
        self._fade_down(leds)

    def _walk_around(self, leds, color, timeout=0.03):
        color_is_fun = callable(color)
        for i in leds:
            self._strip.setPixelColor(i, color(i) if color_is_fun else color)
            self._strip.show()
            self._sleep(timeout)

    @staticmethod
    def _rainbow_wheel(pos):
        return LEDStrip._wheel((int(pos * 256 / LEDStrip._LED_COUNT)) & 255)

    def _startup_animation(self):
        debug("startup animation")
        for c in [LEDStrip.GREEN, LEDStrip._rainbow_wheel, Color(0, 0, 0)]:
            self._walk_around(LEDStrip._LEDS_FROM_MIDDLE, c)

    def _shutdown_animation(self):
        debug("shutdown animation")
        for c in [LEDStrip._rainbow_wheel, LEDStrip.RED, Color(0, 0, 0)]:
            self._walk_around(LEDStrip._LEDS_FROM_MIDDLE, c)
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

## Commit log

2019-08-26 tried to cleanup all the files and dirs (#3)
    [marta.kicad_pcb, marta.sch]
2019-08-26 a the files (#4)
    [led_ring.stl, main_body.stl, pcb_holder.stl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]
2019-08-27 Revise mpg123 (#5)
    * some comments, two timeouts
    * began to work on an error regarding non existing paths and on_error
    * renaming and refactoring.
    [MPG123.py, Marta.py, MusicHandler.py]
2019-10-16 Error handling missing tag (#6)
    * ignore unknown tags in music handler
    * main functions and more
    * stuff
    * mre
    * changed the audio directory structure
    * debug exit on startup script
    * other way of button event handling
    * added time param to button events
    * brightness control
    * refactor yellow and blue in prep for albums
    * preparing albums
    * album structure allowed
    * some kind of working albums i guess
    * albums should completely work by now
    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
    [ButtonLightHandler.py, Buttons.py, LEDStrip.py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]
2019-10-17 added gerber directory to gitignore
2020-02-27 added a few iges and step files
    [led_ring.iges, led_ring.step, main_body.iges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]
